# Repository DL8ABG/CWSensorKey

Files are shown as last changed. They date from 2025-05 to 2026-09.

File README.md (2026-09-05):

# Introduction #

This project contains a kit for a CW-key (or morse key) that works without any mechanical parts but is based on electronic sensors. The idea and initial designs comes from [John, M0UKD](https://m0ukd.com/homebrew/capacitive-cw-touch-key-circuits/) and is extended within this project to a complete kit with housing and a construction of a CW sensor pad.

Credits:
- [John, M0UKD](https://m0ukd.com/homebrew/capacitive-cw-touch-key-circuits/) for the great idea and documentation of this tiny circuit
- [Ken, KM4NFQ](https://github.com/km4nfq/capacitive-touch-key) for his design of the circuit board in [KiCad](https://www.kicad.org/), which was the starting point and inspiration for me on this kit
- Stephan, DO2WWW, for his support during the development of this kit
- [Christian, DJ9PH](https://www.qrz.com/db/DJ9PH), for his support during the development of this kit and for designing the housing for 3D printing. It looks great! He also supported the official setup of the kit by the [AATIS](https://www.aatis.de).

# Available as a kit #

The key and the 3D printed housing are available as kit from AATIS as set number [AS686](https://www.aatis.de).

## pieces needed for the complete kit ##

To assemble the complete kit, you need this:
- the fully assembled electronics board (see "[Electronics](#electronics)" section below)
- the assembled CW Sensor Pad (see "[The CW sensor pad](#the-cw-sensor-pad)" section below)
- housing:
  - metal housing Mammond 1550Q see below ["metal Housing"](#metal-housing)
  - 3D printed housing, see below ["3D printed Housing"](#3d-printed-housing)
- 1 holder for 2 batteries AAA (e.g. from [Reichelt](https://www.reichelt.de/de/de/shop/produkt/batteriehalter_fuer_2_microzellen_aaa_loetfahnen-57125))
- 1 switch (e.g. from [Reichelt](https://www.reichelt.de/de/de/shop/produkt/miniatur-kippschalter_ein-aus_3_a_125_v-359360))
- 1 stereo jack for 3,5mm (e.g. from [Reichelt](https://www.reichelt.de/de/de/shop/produkt/klinkeneinbaubuchse_3_5_mm_stereo-7301))
- material for mounting (see ["Options for mounting"](#options-for-mounting) below)

# Electronics #
The board used in this project was initially designed by [John, M0UKD](https://m0ukd.com/homebrew/capacitive-cw-touch-key-circuits/) and the [KiCad](https://www.kicad.org/) file is based on the work of [Ken, KM4NFQ](https://github.com/km4nfq/capacitive-touch-key). It was changed in shape to fit in the housing and make the wiring easy. 

## Bill of electronic parts ##
- 1 x circuit board
- 2 x IRFML8244TRPBF MOSFETs, SMD SOT-23 (Q1, Q2)
- 2 x AT42QT1011 Touch sensors, SMD (U1, U2)
- 2 x 22K Ohm resistors, SMD 1206 (R1, R2)
- 2 x 0.1uF capacitors, SMD 1206 (C1, C3)
- 2 x 2.2nF capacitors, SMD 1206 (C2, C4)

## Building the circuit board ##

During the soldering, be careful due to the small size of the board and parts, not to make short circuits or bridges of solder. Beyond that and due to the small amount of parts, the soldering is an easy thing.

There are some vias in the board to ensure the GND level to be reliability available on all places needed. The back of the board is connected to GND (except the small places for connecting the wires).

The circuit board from the solder side looks like this (picture generated with KiCad):
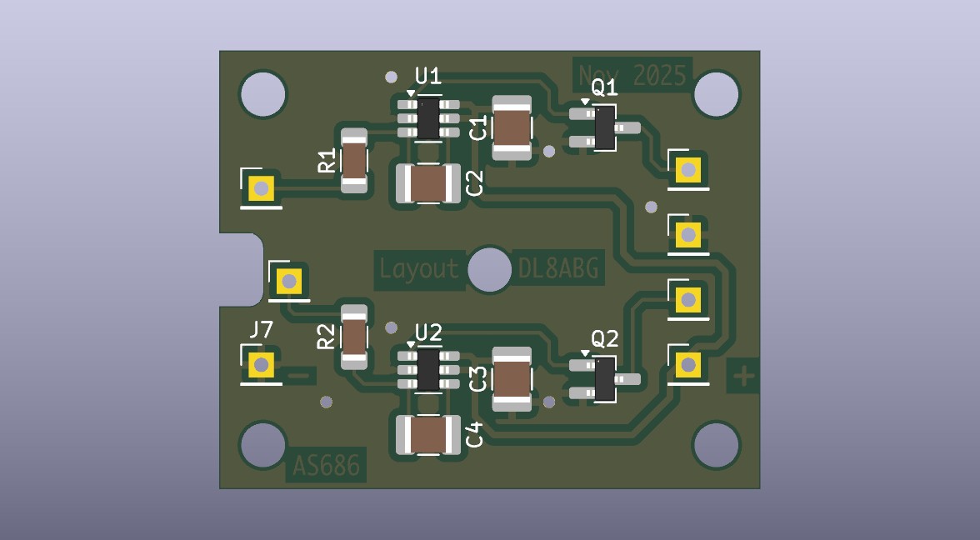
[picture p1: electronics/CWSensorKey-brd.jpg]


The circuit board from the bottom side looks like this (picture generated with KiCad):
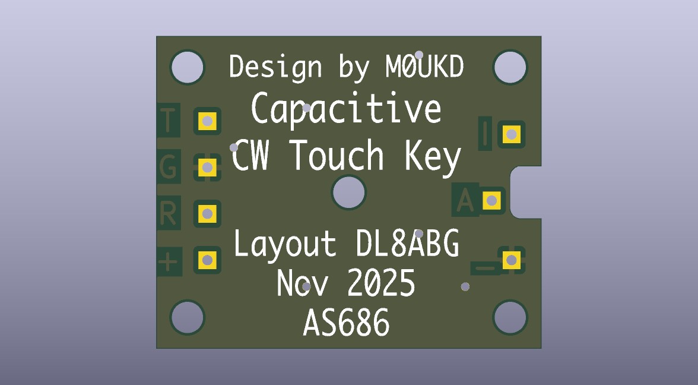
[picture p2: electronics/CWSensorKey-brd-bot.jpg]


The schematic it identical to that of [M0UKD](https://m0ukd.com/homebrew/capacitive-cw-touch-key-circuits/):
The schematic

## Wiring ##

The board has connectors (with its markings on the bottom side which is later visible during installation in the housing): 
- for the sensor pad, marked with I for dit and A for dah
- for the connector, marked with T for tip, R for ring and G for ground of the 3 pin 3,5mm plug
- power supply, marked with + and -

All electrical parts together look like this:
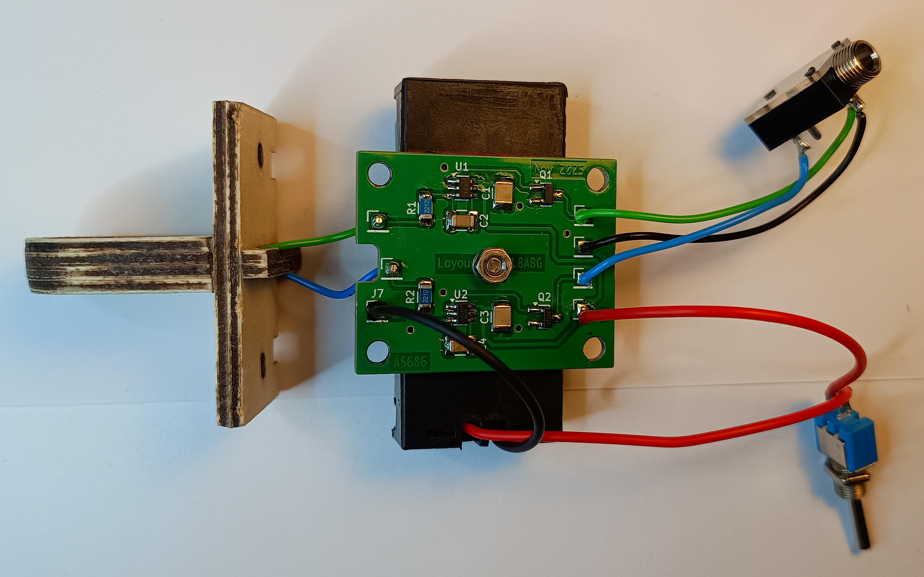
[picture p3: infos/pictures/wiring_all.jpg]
Wiring


You see the battery holder mounted on the bottom side of the board and the switch is inserted in the + cord.

# Mechanics #

## The CW sensor pad ##
The pad is designed to use coins as sensor fields. For Germany/Europe Euro coins are easily accessible. That was the reason, why 10 Euro-Cent coins will fit in the sensor (diameter 19.75mm, width nearly 2mm). If you intend to use other dimensions, adapt the [FreeCAD](https://www.freecad.org/) files as needed.

The sensor pad consists of multiple pieces of 2mm wood to be cut by e.g. a laser cutter. In the development of this kit I found, that the "2mm" plates are only 1.9 mm in with, so the holes for fitting together the single plates are designed for this width. If you have really 2.0 mm wide plates, use a file or a piece of sand paper to adjust the width of the holes to your need.

The sensor pad consists of 6 pieces of wood:
- 2 rectangular holder plates
- 2 middle plates which differ in the position of the "wire channel" from each other
- 2 side plates with round holes to fit the coins

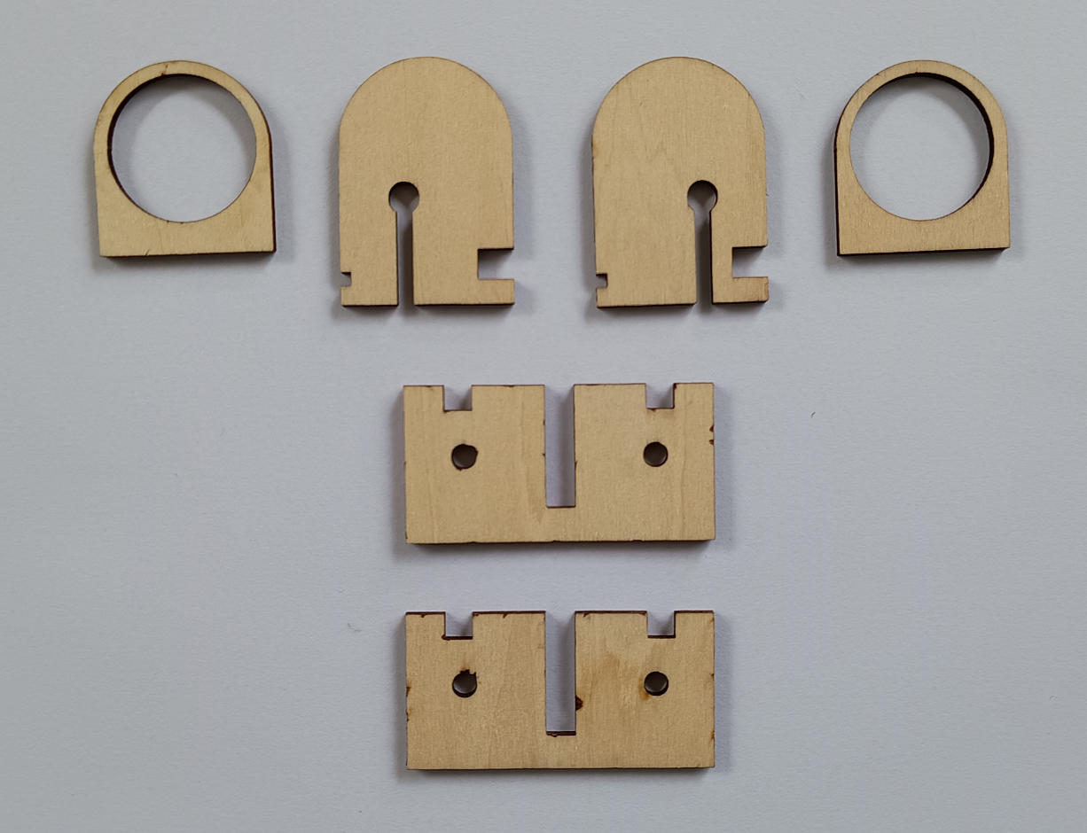
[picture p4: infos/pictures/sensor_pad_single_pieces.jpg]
So this is, what you have


First step:
- glue together the 2 rectangular holders
- glue together the 2 middle plates

Take care that the each two pieces lie exactly on top of each other!

After having glued the first parts, it should look like this:
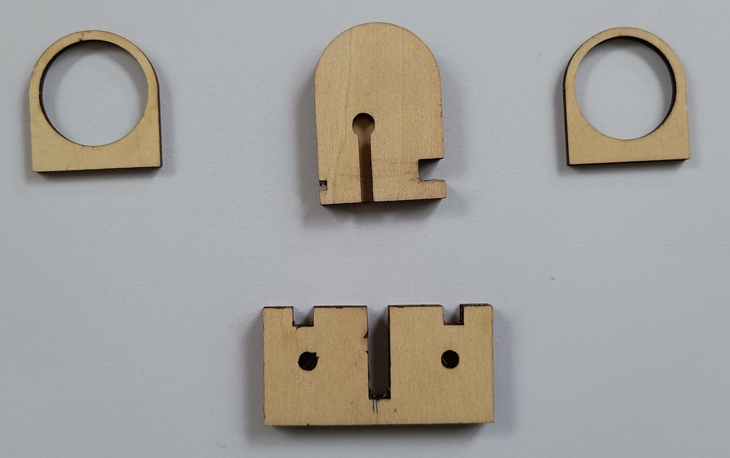
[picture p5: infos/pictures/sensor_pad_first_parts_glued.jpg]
After having glued the first parts, it should look like this


Now glue the side plates on each side of the middle plates. Also here, take care that they lie exactly in the right position.

Now you have two pieces:
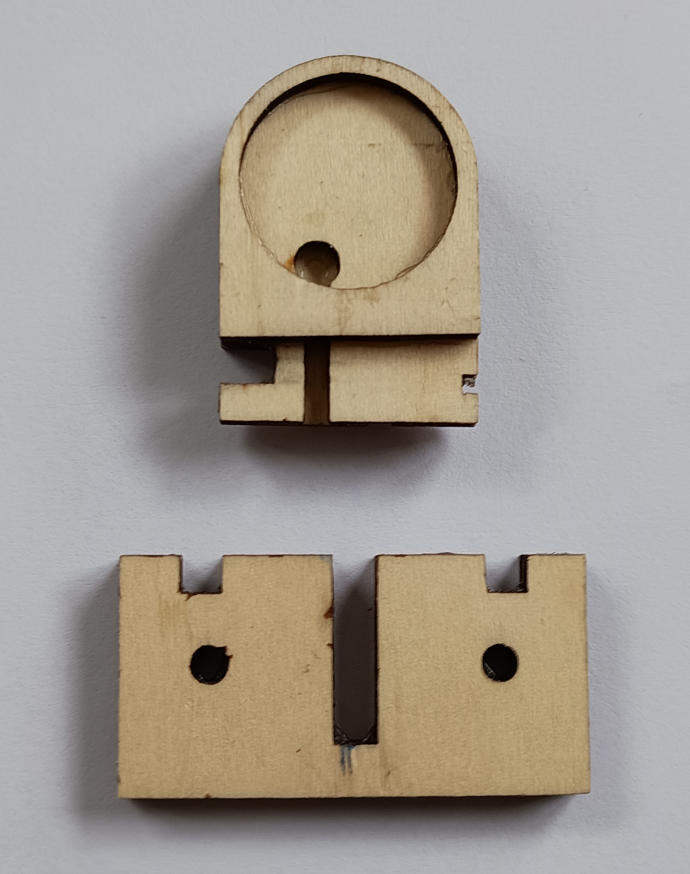
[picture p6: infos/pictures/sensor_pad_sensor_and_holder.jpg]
Now you have two pieces


Now set the holder in the hole at the end of the pad. Take care, that it is directly connected to the back side of the side plates. This ensures the correct alignment in up/down direction. Also take care, that the sensor pad part and the holder have a good rectangular orientation to ensure a correct alignment to the left and right.

Your assembled sensor pad should look like this:
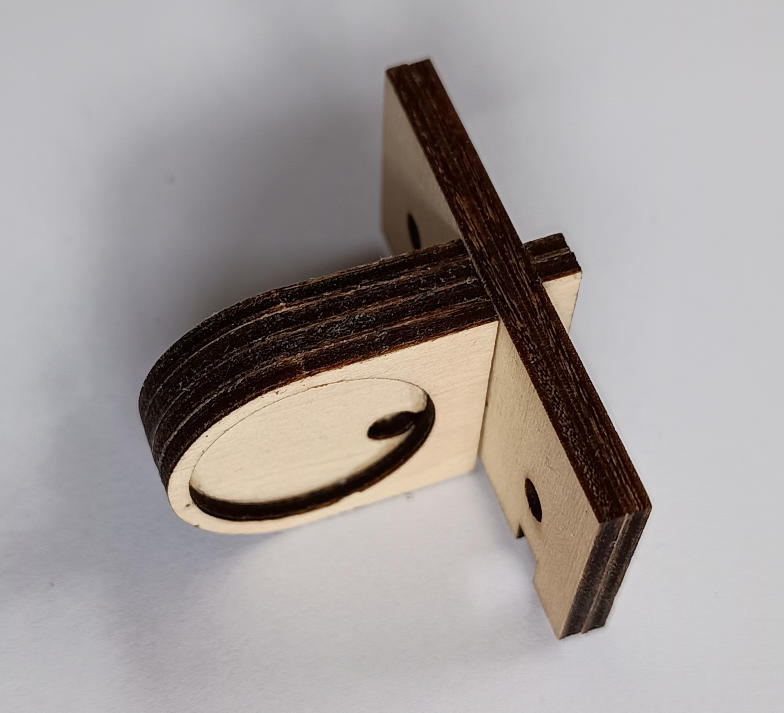
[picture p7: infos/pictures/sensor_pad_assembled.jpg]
The sensor pad is now assembled


The next step is to prepare the coins. Solder the wires on them (next to the edge). The solder spot should be not to big (it must fit in the small hole below the coin in the pad). Prior to soldering, clean the surface of the coin on the place you want to solder with a screwdriver to remove the oxide layer that normally covers the coin.
It should look like this at the end of this step:
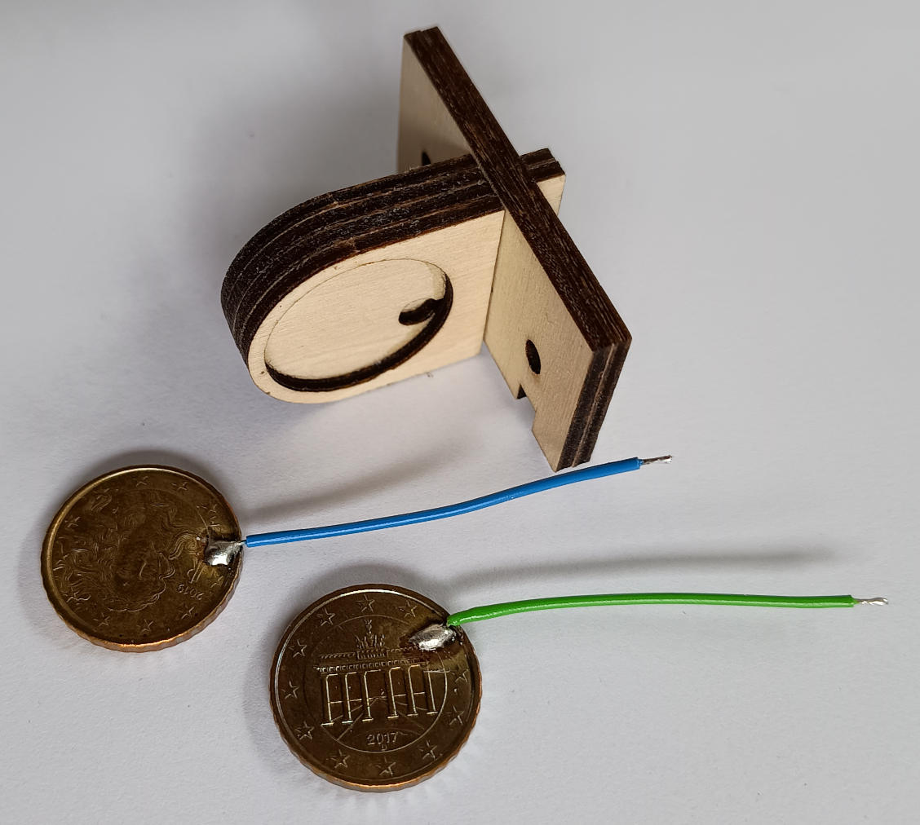
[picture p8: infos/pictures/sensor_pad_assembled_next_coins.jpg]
The sensor pad next to the coins


Now insert the wires in the small holes below the holders of the coins, so that they exit the pad at the back side. The coins should fit perfectly in the holder plates and it should look like this. If there are residue of the glue in the holes for the wires, clean them with a thin drill.
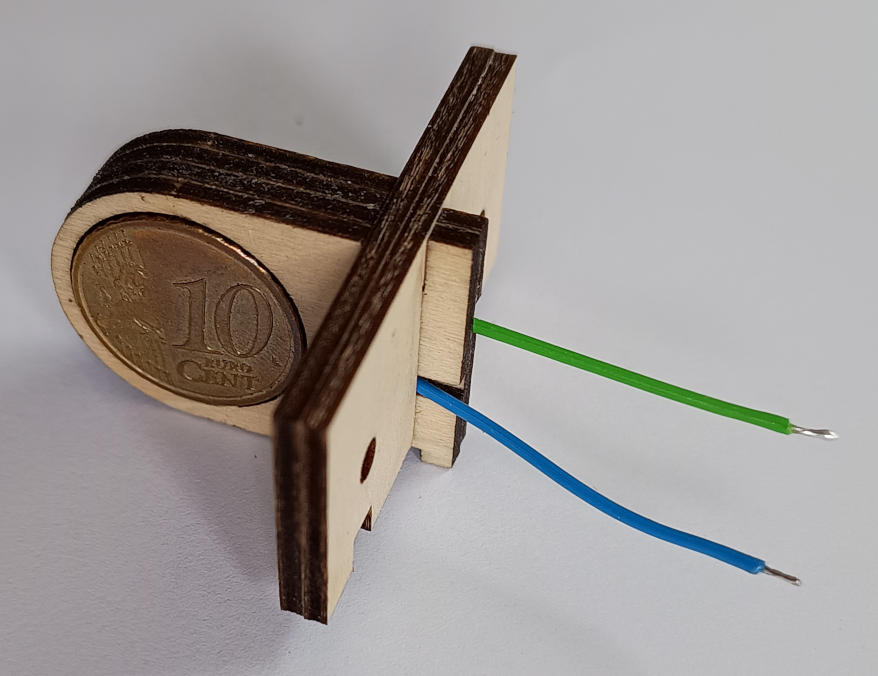
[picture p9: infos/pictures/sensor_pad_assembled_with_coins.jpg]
The sensor pad with coins


Glue the coins in the holder plates and/or use some plastic tape to prevent them from falling out. With that, your sensor pad is complete and can be installed in the housing.

## Metal housing ##

For a metal housing, you need the following components:
- the housing Mammond 1550Q (e.g. from [Reichelt](https://www.reichelt.de/de/de/shop/produkt/alugehaeuse_1550_q_60_x_55_x_30_mm_aluminium-221407))
- 4 distance bolts M2,5 with length 5mm (e.g. from [Reichelt](https://www.reichelt.de/de/de/shop/produkt/distanzbolzen_5_mm_m2_5-236284))
- 4 screws M2,5 x 5mm
- 8 washers for M2,5
- 8 lock washers for M2,5
- 4 nut screws M2,5

- for mounting the CW Sensor Pad, you need:
  - 2 screws M3 x 10mm
  - 2 washers for M3
  - 2 lock washers for M3
  - 2 nut screws for M3

Preparing the Mammond 1550Q

### Hole for sensor paddle ###

First mark the middle of the _wider_ side (green on the next picture).

Than mark nearly 2mm to each side (blue on the next picture). In sum it must meet the width of your paddle. It is ok, if it is a tight fit.
The hight of the marking is 23mm to meet the height of the paddle.

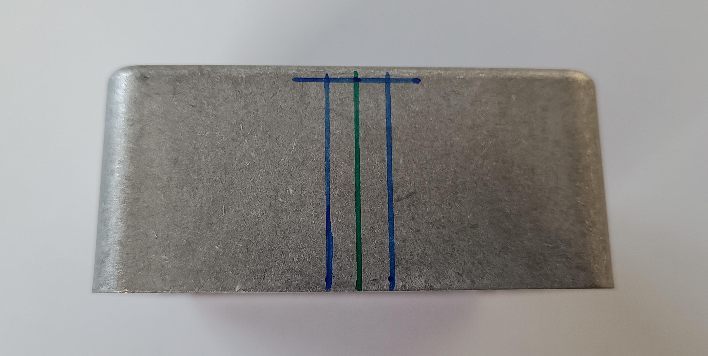
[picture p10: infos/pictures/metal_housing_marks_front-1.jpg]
Markings on the front side


Than take a metal saw to cut out the opening along the outer lines (the blue ones in the picture above). Use a key file to make the opening accurately rectangular.

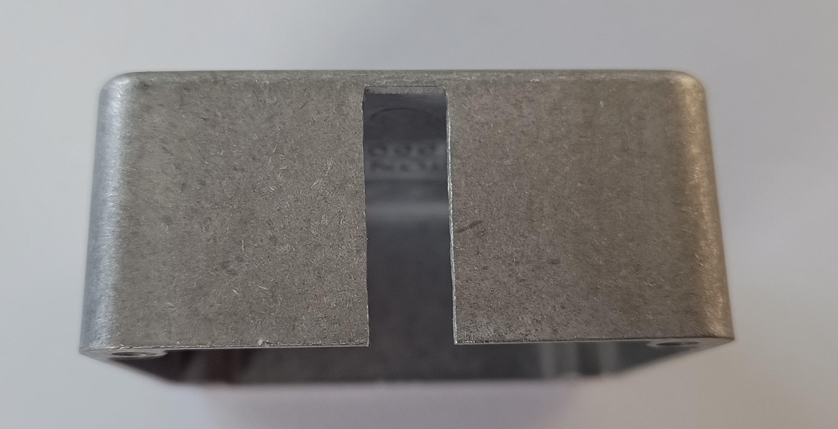
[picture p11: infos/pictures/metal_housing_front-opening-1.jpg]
Opening for the paddle


Next mark the hole for the paddle holder. You can measure it (12mm from the bottom and 30mm apart). To make sure it fits with your holder, additionally place the holder it the opening you just prepared and use the holes in the wooden plates to mark points for the holes (or verify your measurement).

Than drill the holes to fit with the 3mm screws. If you use countersunk screws, also drill the lowering.

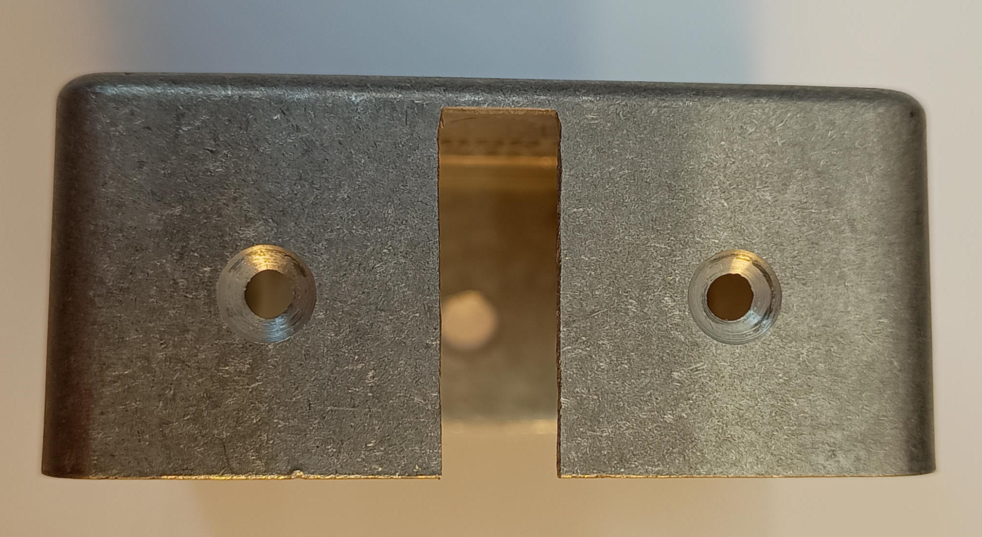
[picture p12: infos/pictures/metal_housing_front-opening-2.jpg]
Opening for the paddle and holes for screws


### Holes for the board ###

Place the paddle in its position (you can also use the screws to temporarily holt it in place). Than lay the circuit board inside the housing and position it so that the holder of the paddle protrudes into the recess.

To have enough room for the switch and connector at the back side, place the circuit board as tight as possible next to the paddle holder.

Mark the points for the holes and drill them to fit the 2.5mm screws. As well here: if you use countersunk screws, also drill the lowering.

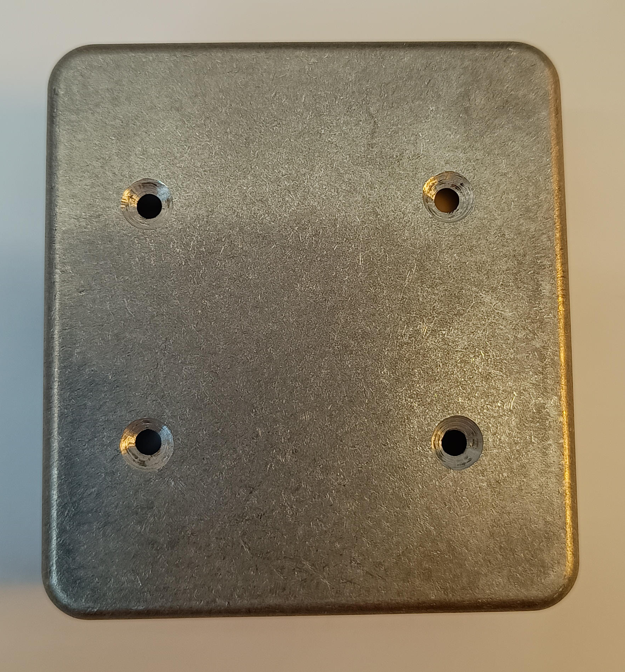
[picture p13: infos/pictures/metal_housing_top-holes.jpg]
Holes for the screws to hold the circuit board


### Holes for connector and switch ###

The positioning of the holes for the connection and the switch is somewhat difficult. 

Depending of the parts you use, they can either be positions on the side next to the circuit board or you can position the connector centered "above" the circuit board and only the switch side next of it.

Be careful to leave enough space for the circuit board with the bolts holding it and the batterie holder, which is placed on top of the circuit board.

This picture shows the installation side next to the board (on one of the prototypes):
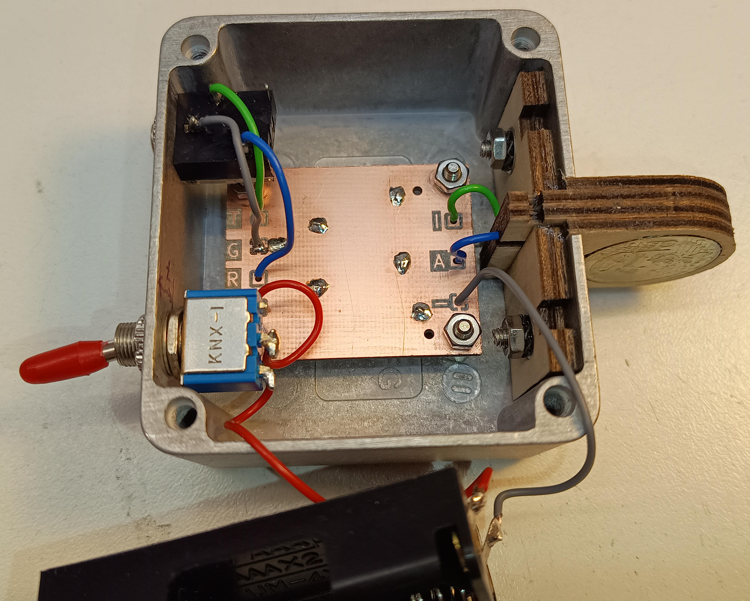
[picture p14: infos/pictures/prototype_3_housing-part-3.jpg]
Connector and switch out of center of the housing


This picture shows the holes for the connector centered and the switch at the side:
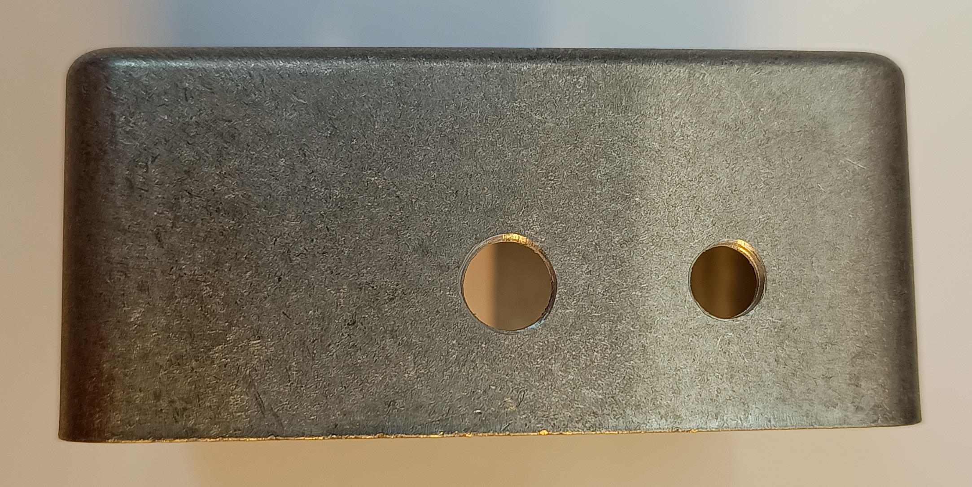
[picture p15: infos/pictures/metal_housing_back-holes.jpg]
Connector centered and switch out of center of the housing


So you can place it as you like it best. For example: according to the hand you want to use the key, place the switch on the side "away" from you to have it out of your way during usage.

### Putting the pieces in the metal housing ###
Here you see the suggested mounting order seen on the third prototype. How to find the places for the holes in the housing will be explained here in a later version of the README.

First set the bolts for holding the board in the housing using lock washers to keep it tight:
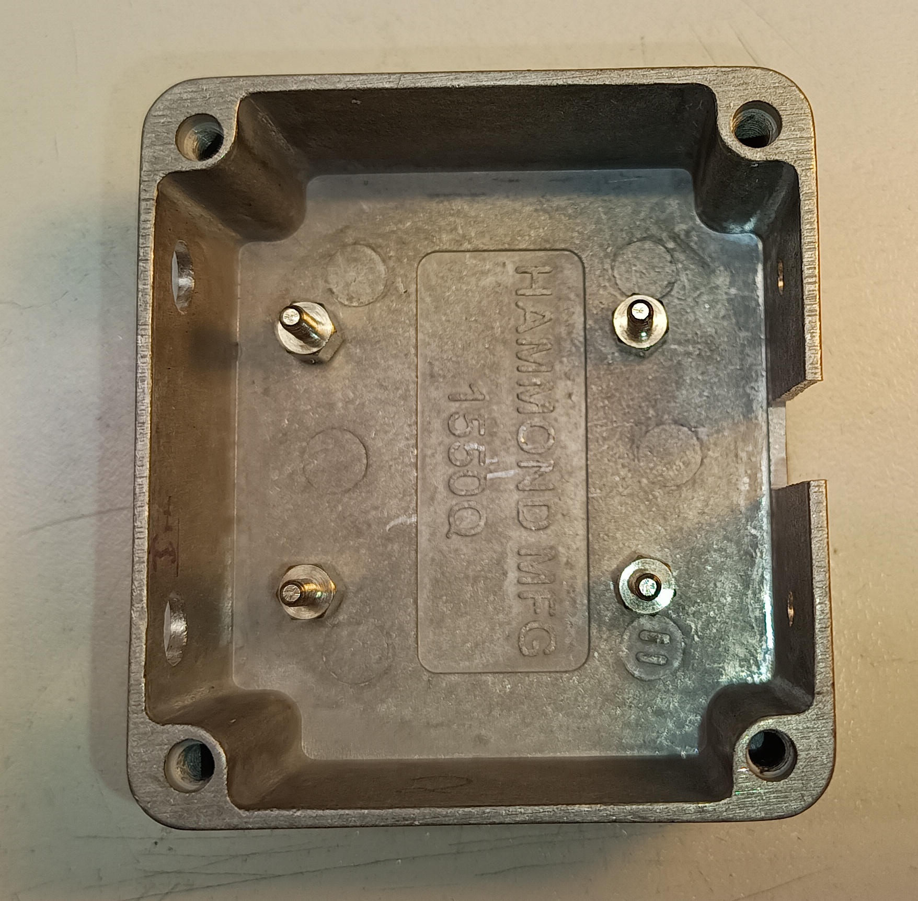
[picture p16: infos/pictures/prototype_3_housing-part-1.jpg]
housing with bolts


Second fix the board on the bolts with the nuts (including washers):
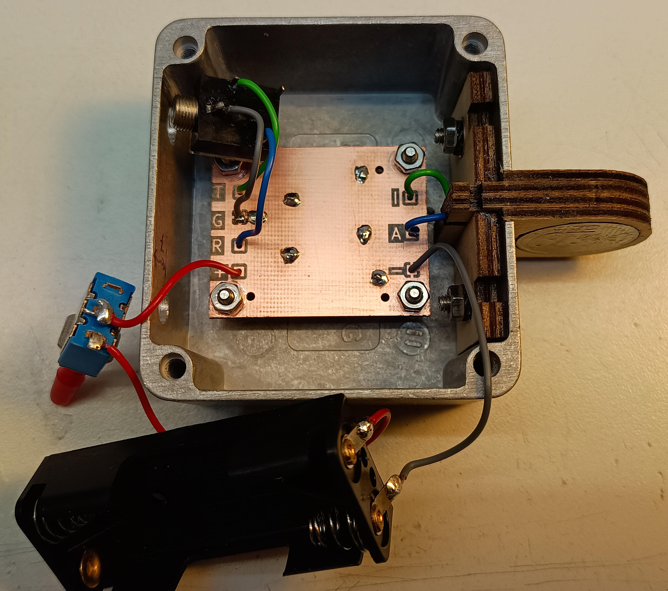
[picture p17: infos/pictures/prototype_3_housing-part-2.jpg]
board on the bolts


Then fix the sensor pad, the connector and the switch in its holes:
additional components fixed

As the last step, mount the battery holder on the board. 

There are two options:
- using some double-sided adhesive tape: Use strong adhesive tape, preferably one with a layer of silicone, which is often recommended for outdoor use.
- use the hole in the center of the board to screw the battery holder to the board. Therefore, you need an _additional_ M2.5 screw with plate, washer plate and nut (not mentioned in the part list on top of the page)

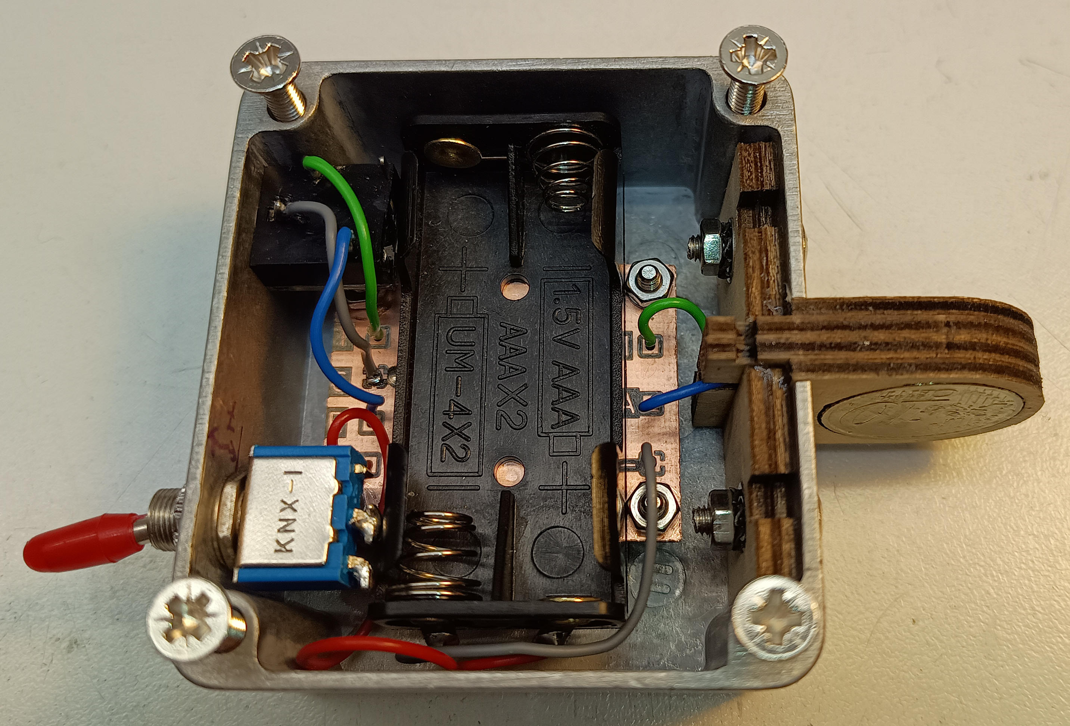
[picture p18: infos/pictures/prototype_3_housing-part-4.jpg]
battery holder fixed


Now you can close the housing and your key is complete (or you want to add magnets as a mounting option, what ist explained in the next section).

## 3D printed housing ##

For the 3D printed housing you need the following:
- 3D printed housing, a bottom and a top part (files to be found under mechanics/housing)
- 12 press-fit sleeves M3
  - 4 of them only if you want to attach magnets below the hosing (see ["Options for mounting"](#options-for-mounting) below)
- 4 screws M3 x 8mm (holding the circuit board)
- 4 screws M3 x min 10mm (connecting the two parts of the hosing)

- for mounting the CW Sensor Pad, you need:
  - 2 screws M3 x 10mm
  - 2 washers for M3
  - 2 lock washers for M3
  - 2 nut screws for M3

The wiring is identical to that when using the metal housing.

### The press-fit sleeves ###

First, the press-fit sleeves must be installed. It is recommend to use an installation aid to ensure that they are pressed in straight. If this is not available, please use a conical soldering iron tip and hold it absolutely straight.

The press-in nuts of the magnet should also be pressed in from the INSIDE to ensure a secure hold.

### The sensor pad ###

The sensor pad is inserted in the rectangular hole in the same way as for the metal housing. The screws are inserted from the outside with plates and washer plates and nuts inside. 

### The electronics ###

This step is similar to that of the metal housing:
- mount the battery holder on the circuit board
- mount both inside the housing using 4 screws

### Connector and switch ###

The holes are prepared in the 3D printed housing. Just insert them and use their screws to fixate them. Some force is needed to make them hold. Be careful that it is tight enough but not to tight to damage them.

## Options for mounting ##
As the kit is intended for universal use, you can decide for which purpose you like to use it in your case. It can be used for portable operation (due to its small size and good closure thus resistance against dirt) or for use in your shack.

For portable use, you can mount strong magnets on the bottom side of the housing. With them you can attach the key to any (magnetic) surface you like (your portable TRX, a metal case, ...). This is the way, many portable keys work (like those from [Palm](https://www.eham.net/reviews/view-product/11153) or other companies).

Possible sources for the magnets are (listed as *examples*)
- [Supermagnete](https://www.supermagnete.de/neodym-magnete-zum-anschrauben/quadermagnet-zum-anschrauben-40-x-20-x-4mm_CS-Q-40-20-04-N)
- [Amazon](https://www.amazon.de/dp/B08F54YGC9)

This is, how it can look:
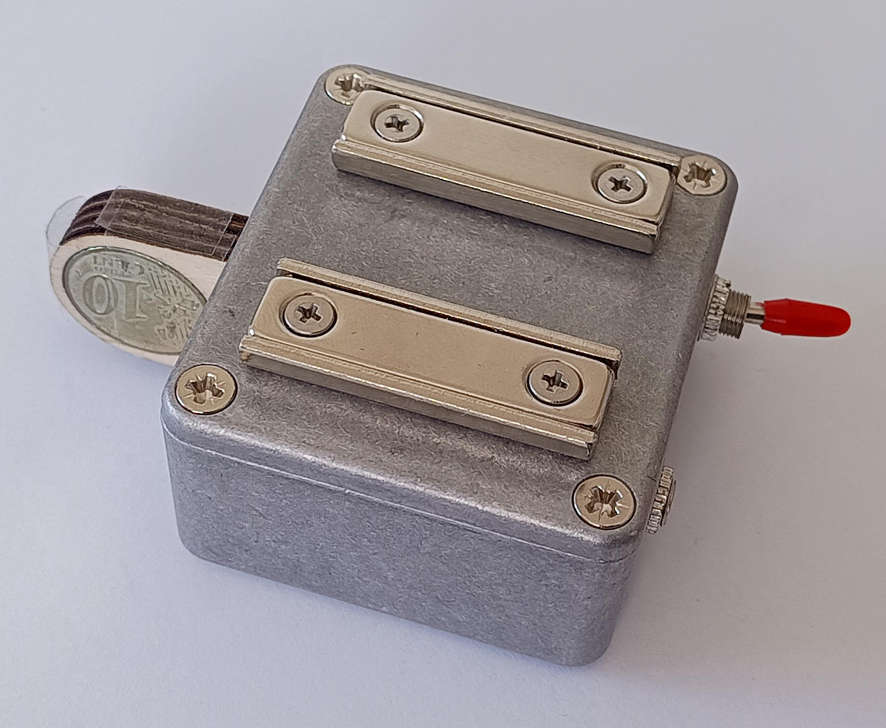
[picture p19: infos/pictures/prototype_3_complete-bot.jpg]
magnets on the bottom side of the housing


For use only in your shack, you can mount the bottom side of the key directly to a heavy item like a metal plate (e.g. steal with 8cm x 8cm x 2cm) or a stone plate, with probably looks great). For this mounting, you drill holes according to the holes for the screws in the housing through yor item and replace the screws of the housing with longer ones suitable for your item dimension. In this way you mount your item, the bottom of the housing and the top of the housing in once.

# Hints #
## Battery falling out of holder when mounting the key with strong magnets ##

If you have very strong magnets, it can happen, that the batteries fall out of its holder if you attach the key to a surface. To avoid this, put some foam on top of the batteries to tighten their position together with the bottom of the housing.

# History #

## First Prototype ##
The first prototype is shown here. It was my first try on how good the circuit works and was made by parts I found after receiving the board. I also verified with this construction, that coins are suitable sensor pads (here 5 Euro-Cent coins).
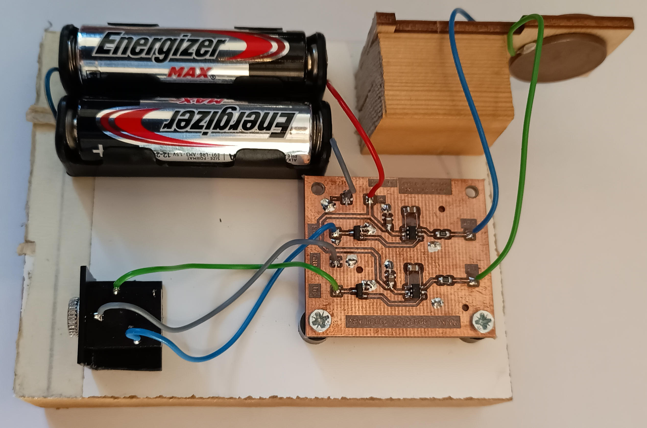
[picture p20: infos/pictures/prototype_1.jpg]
first prototype of the kit


## Second Prototype ##
I changed the first prototype by replacing the "testing" sensor pad with first example made from laser cutted wood.
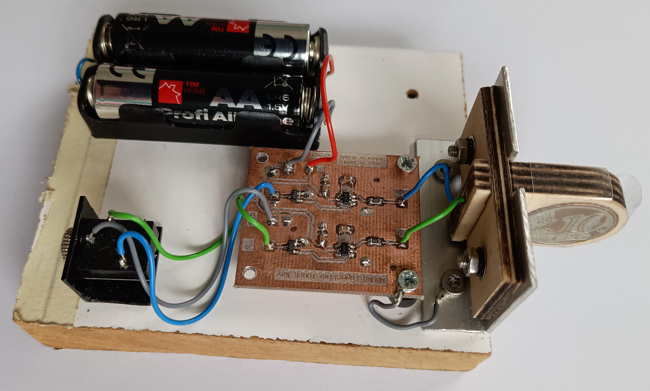
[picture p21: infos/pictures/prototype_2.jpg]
second prototype of the kit


## Third prototype ##
After some changes to the board to reduce its size and place the solder pads on either sides, the third prototype became available. Here you see its construction.

This is the electronic connected with all external components:
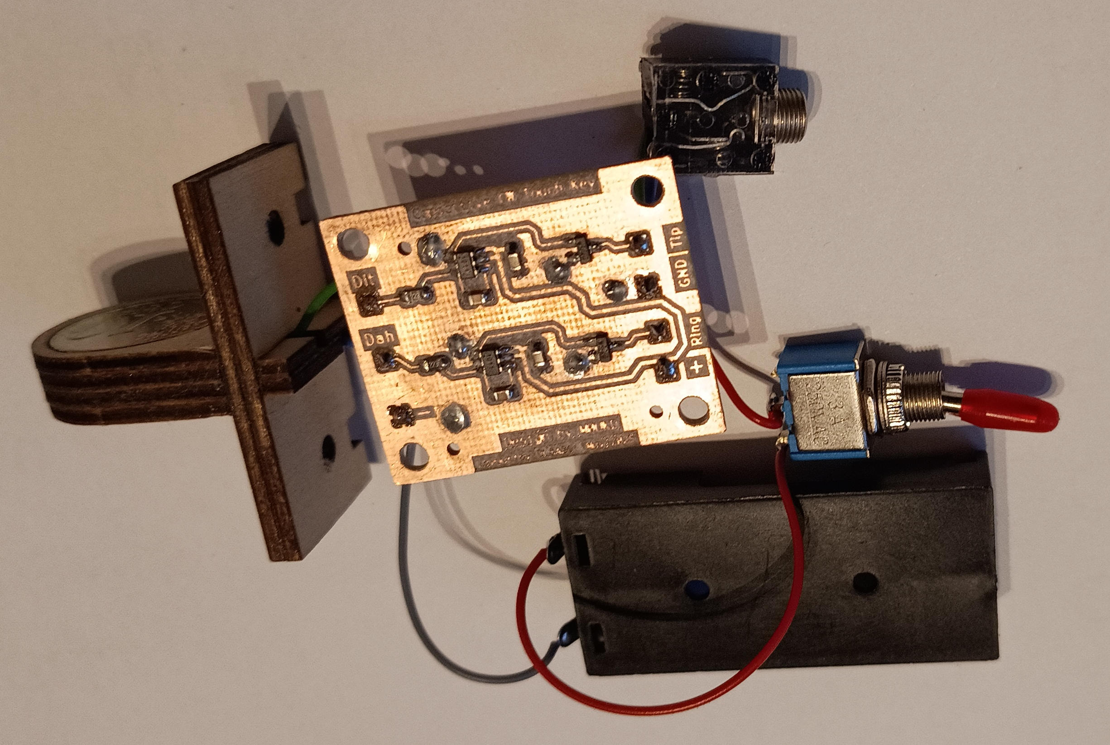
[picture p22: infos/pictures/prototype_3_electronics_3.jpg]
the electronic seen from the solder side


This is the same showing the bottom side of the board (where the battery holder is glued on):
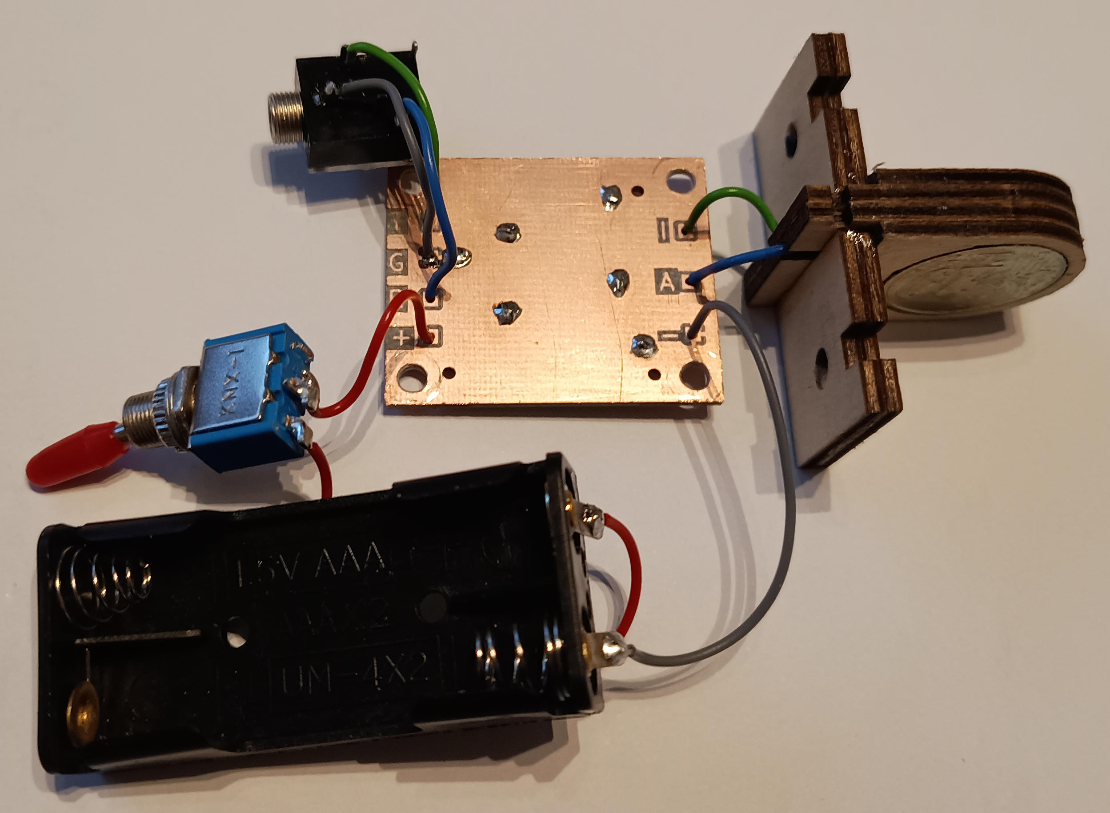
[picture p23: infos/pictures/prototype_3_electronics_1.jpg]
the electronic seen from the bottom side


And theses are pictures of the whole key in its housing:
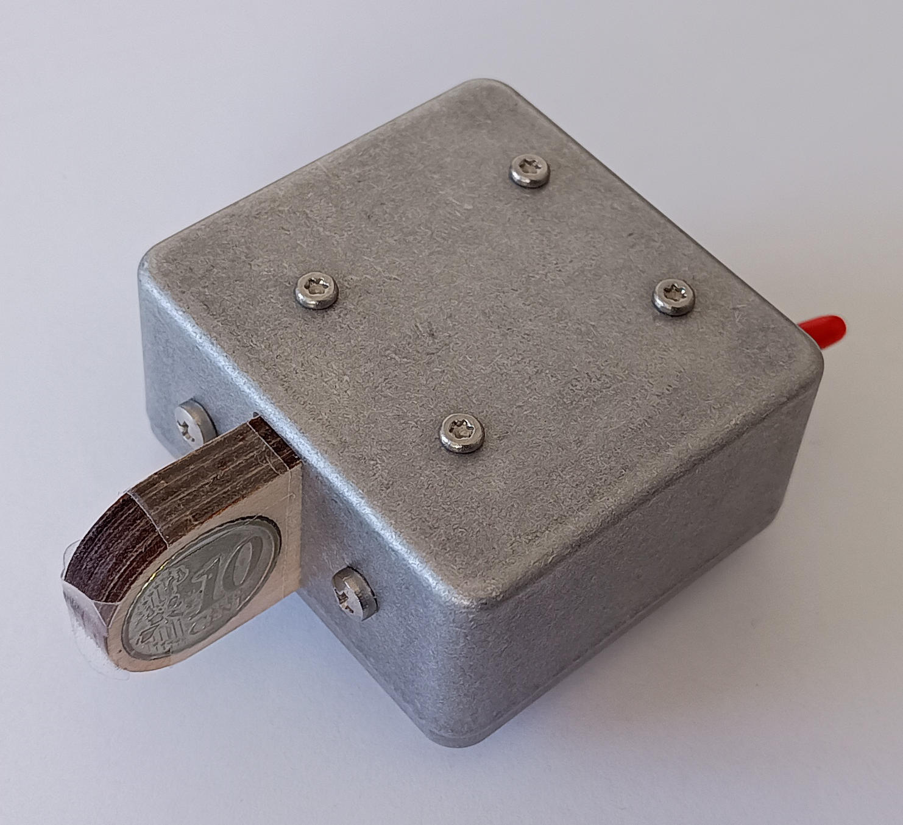
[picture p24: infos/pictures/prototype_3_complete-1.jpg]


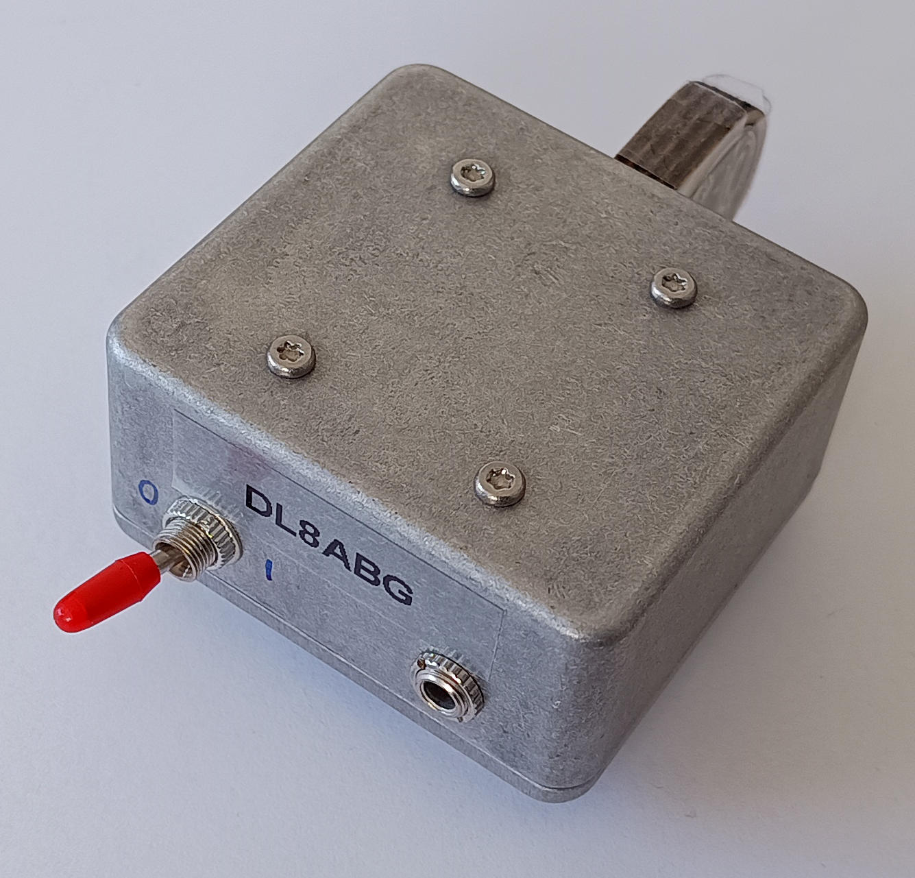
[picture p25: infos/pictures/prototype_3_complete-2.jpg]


## Version 4 ##
As this is more than an "prototype" I call ist version 4 ;-)

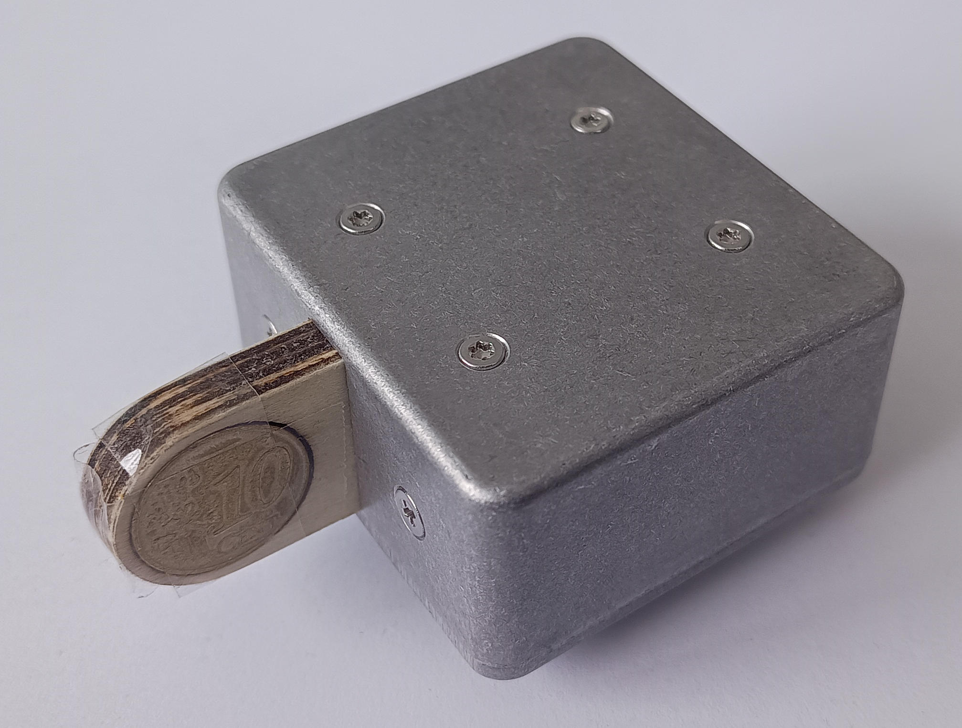
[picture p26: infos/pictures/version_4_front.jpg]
the key seen from front


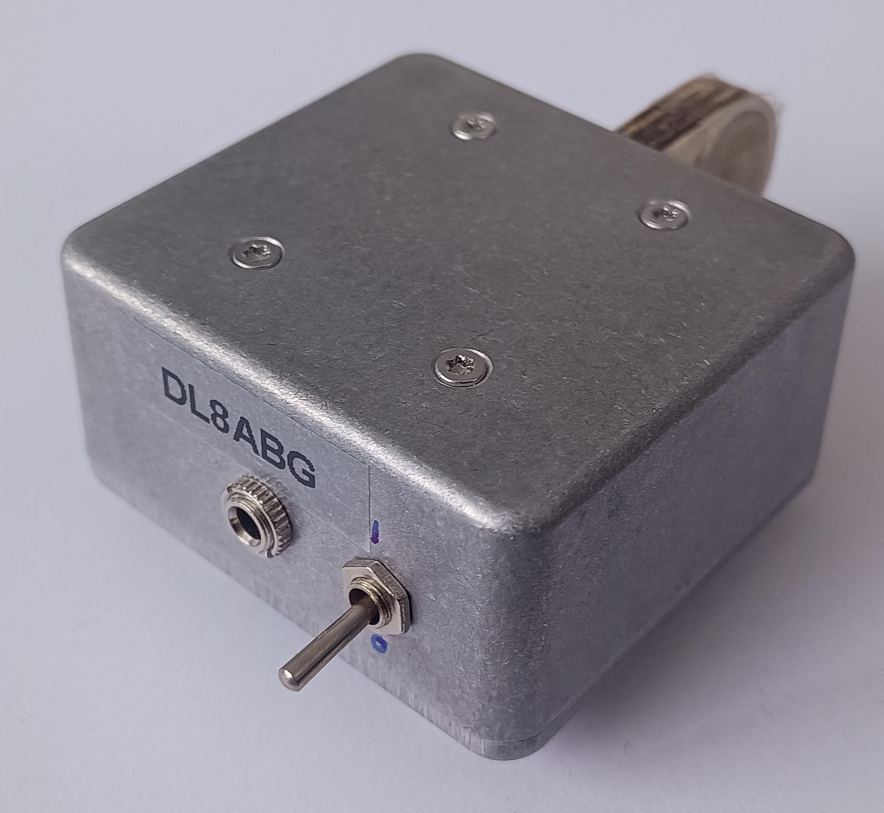
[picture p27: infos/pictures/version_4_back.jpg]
the key seen from back


# Responsibility #
This kit is build by **you**. You are responsible for all safety and legal aspects on setup and operation!! 

The author is not liable for anything, as he only shows his ideas on how such a sensor key can be build.

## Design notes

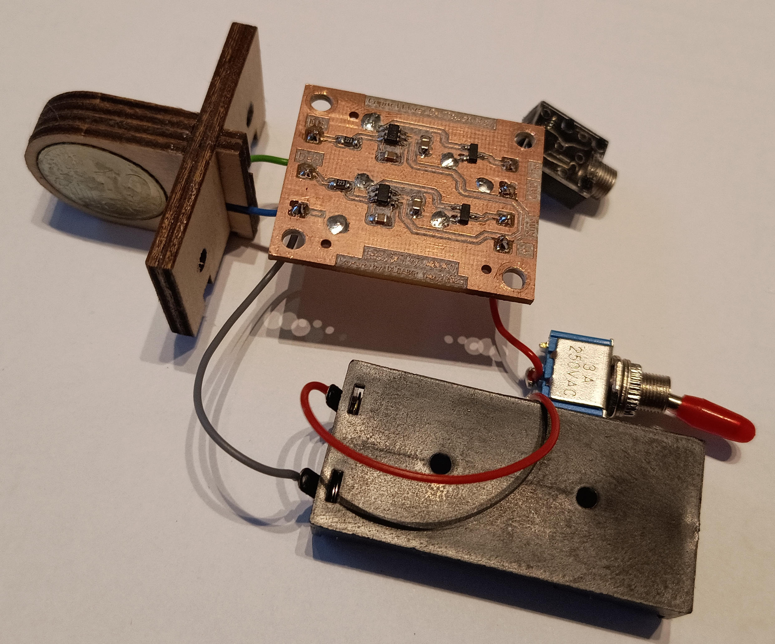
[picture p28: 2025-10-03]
infos/pictures/prototype_3_electronics_2.jpg

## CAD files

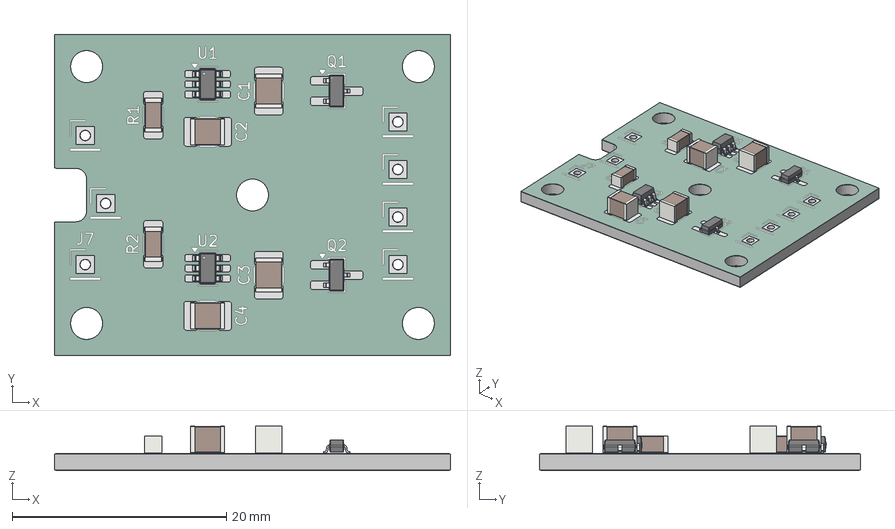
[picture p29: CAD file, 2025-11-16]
electronics/CWSensorKey-brd-3D.step
37.0 x 30.0 x 4.17 mm
C_1210_3225Metric x 4
SOT-23-6 x 2
SOT-23 x 2
C_1206_3216Metric x 2
CWSensorKey_copper
CWSensorKey_pad
CWSensorKey_via
CWSensorKey_silkscreen x 2
CWSensorKey_soldermask x 2
CWSensorKey_PCB

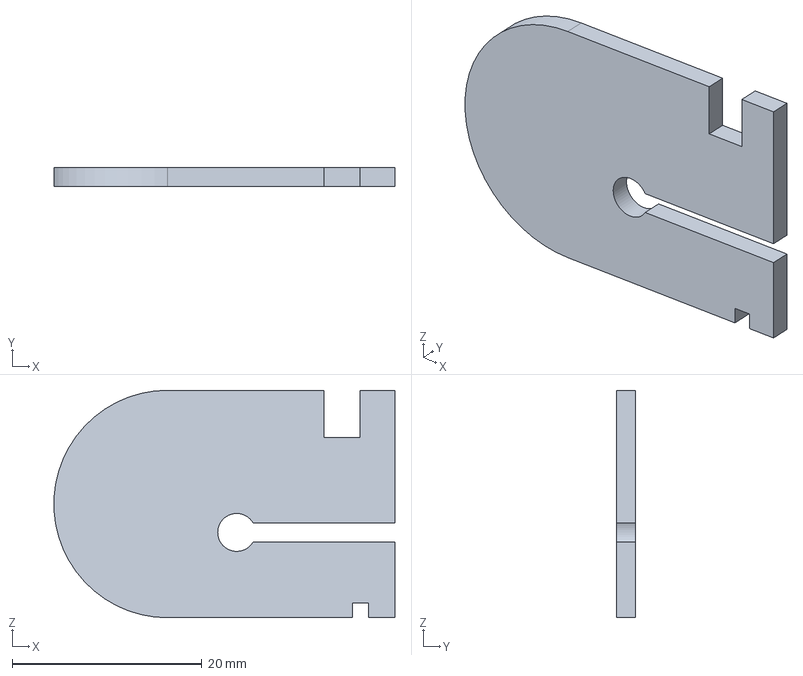
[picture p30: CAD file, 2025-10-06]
mechanics/cwpad/CW-Pad-Middle-Dah.FCStd
36.0 x 2.00 x 24.0 mm

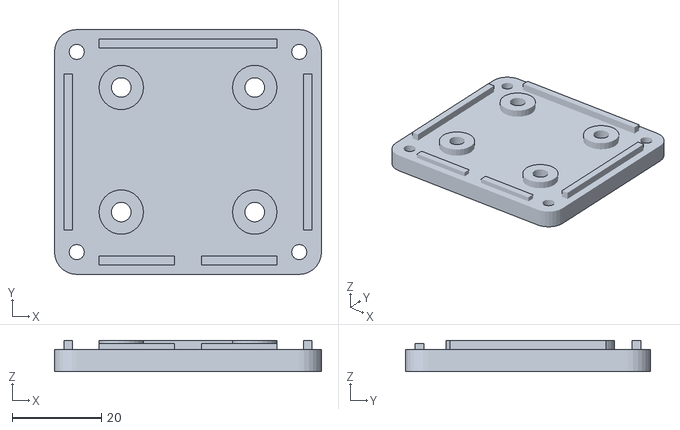
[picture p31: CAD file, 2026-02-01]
mechanics/housing/AS686_Bottom.stl
60.0 x 55.0 x 7.00

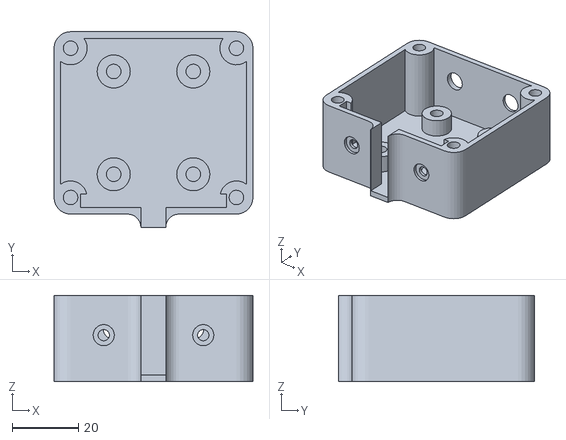
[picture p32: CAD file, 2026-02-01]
mechanics/housing/AS686_Top.stl
60.0 x 59.0 x 26.0

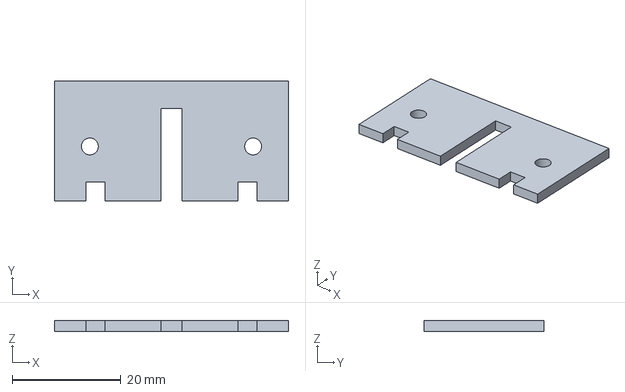
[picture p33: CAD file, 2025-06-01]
mechanics/cwpad/CW-Pad-Holder.FCStd
43.0 x 22.0 x 2.00 mm

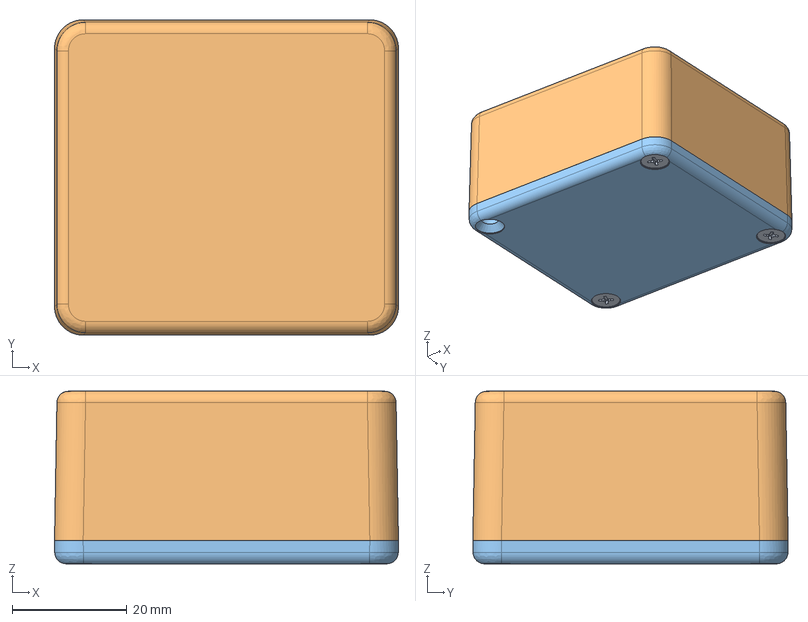
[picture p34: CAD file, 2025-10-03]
mechanics/cwpad/ignore/Housing-Box-with-Parts.FCStd
60.0 x 55.0 x 30.1 mm
SC1550 (screw M3.5-0.6X 12mm FH) x 3
Lid

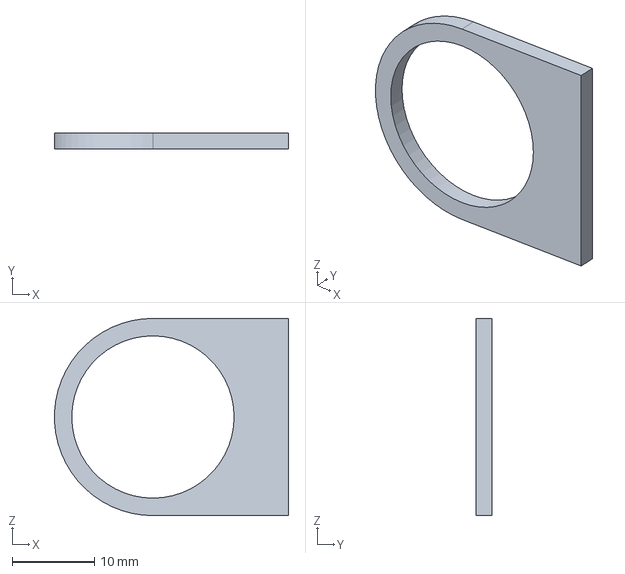
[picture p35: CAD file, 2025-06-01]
mechanics/cwpad/CW-Pad-Side.FCStd
28.5 x 2.00 x 24.0 mm

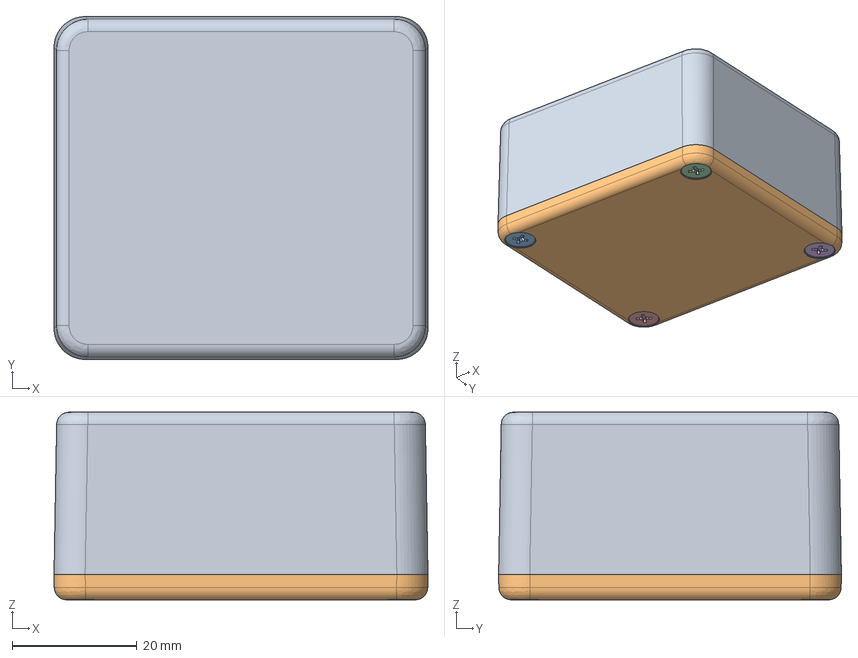
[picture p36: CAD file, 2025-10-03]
mechanics/cwpad/ignore/Housing-Box.FCStd
60.0 x 55.0 x 30.1 mm
1550Q BOX
1550Q LID
SC1550 (screw M3.5-0.6X 12mm FH)
SC1550 (screw M3.5-0.6X 12mm FH)001
SC1550 (screw M3.5-0.6X 12mm FH)002
SC1550 (screw M3.5-0.6X 12mm FH)003

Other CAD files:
mechanics/cwpad/ignore/CWSensorKey-Assembly.FCStd
mechanics/cwpad/ignore/Pad-Assembly.FCStd
mechanics/CWSensorKey-brd-3D.step
mechanics/cwpad/CW-Pad-Middle-Dit.FCStd
mechanics/cwpad/ignore/CW-Pad-Basic.FCStd
mechanics/cwpad/ignore/1550Q.stp
electronics/CWSensorKey-brd-3D.stl
mechanics/cwpad/ignore/1550Q.igs

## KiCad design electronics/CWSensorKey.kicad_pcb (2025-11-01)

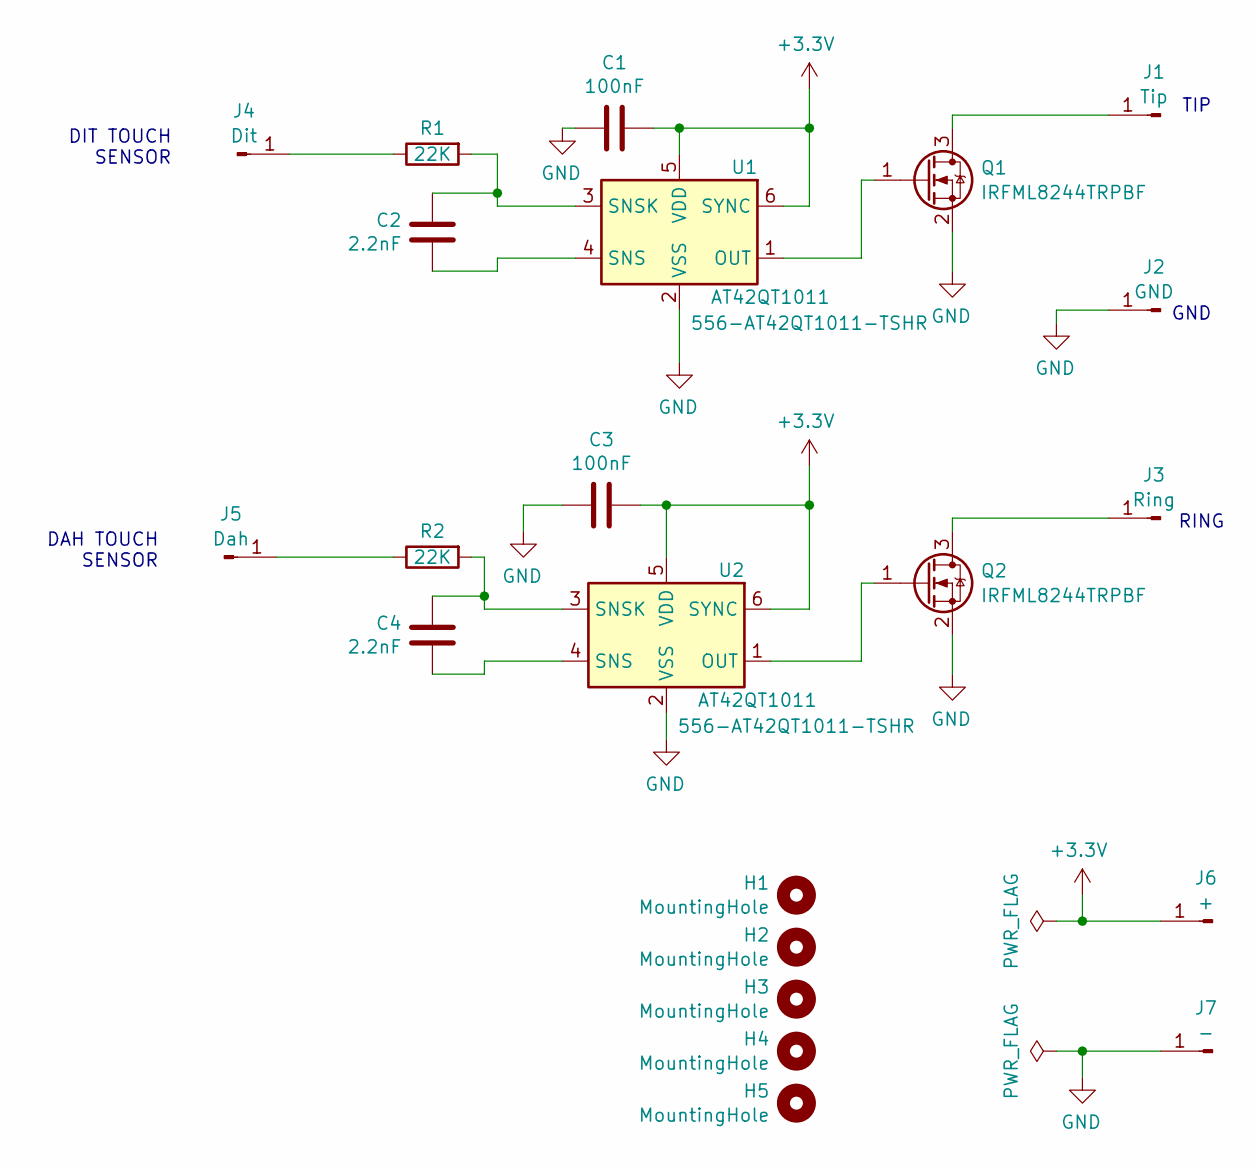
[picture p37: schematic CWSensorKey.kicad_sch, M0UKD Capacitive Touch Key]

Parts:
C1, C3: 100nF; C_1210_3225Metric_Pad1.33x2.70mm_HandSolder
C2, C4: 2.2nF; C_1210_3225Metric_Pad1.33x2.70mm_HandSolder
H1, H2, H3, H4, H5: MountingHole; MountingHole_3mm
J1: Tip; PinHeader_1x01_P2.54mm_Vertical
J2: GND; PinHeader_1x01_P2.54mm_Vertical
J3: Ring; PinHeader_1x01_P2.54mm_Vertical
J4: Dit; PinHeader_1x01_P2.54mm_Vertical
J5: Dah; PinHeader_1x01_P2.54mm_Vertical
J6: +; PinHeader_1x01_P2.54mm_Vertical
J7: -; PinHeader_1x01_P2.54mm_Vertical
Q1, Q2: IRFML8244TRPBF; SOT-23_Handsoldering
R1, R2: 22K; C_1206_3216Metric_Pad1.33x1.80mm_HandSolder
U1, U2: AT42QT1011; SOT-23-6_Handsoldering

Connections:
+3.3V: C1.2, C3.2, J6.1, U1.5 (VDD), U1.6 (SYNC), U2.5 (VDD), U2.6 (SYNC)
GND: C1.1, C3.1, J2.1, J7.1, Q1.2 (S), Q2.2 (S), U1.2 (VSS), U2.2 (VSS)
unnamed: J1.1, Q1.3 (D)
unnamed: J3.1, Q2.3 (D)
unnamed: J4.1, R1.1
unnamed: J5.1, R2.1
unnamed: Q1.1 (G), U1.1 (OUT)
unnamed: Q2.1 (G), U2.1 (OUT)
unnamed: C2.2, U1.4 (SNS)
unnamed: C2.1, R1.2, U1.3 (SNSK)
unnamed: C4.2, U2.4 (SNS)
unnamed: C4.1, R2.2, U2.3 (SNSK)

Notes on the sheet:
GND
DAH TOUCH SENSOR
TIP
RING
DIT TOUCH SENSOR

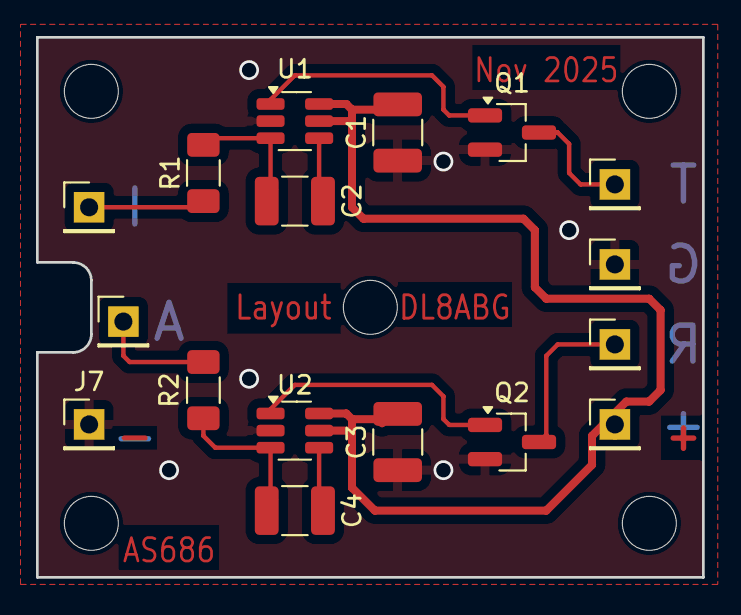
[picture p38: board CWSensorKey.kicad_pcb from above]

Board: 2 copper layers, 37.0 x 30.0 mm, 22 parts (0 on the bottom side), 12 nets.

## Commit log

2025-05-17 Added first files
    [1550Q.igs, 1550Q.stp, CW-Pad-Basic.FCStd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]
2025-05-23 Changed CW-Pad and added script for 2D generation in FreeCAD
    [CW-Pad-Basic.FCStd, CW-Pad-Holder.FCStd, CW-Pad-Middle-Dah.FCStd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]
2025-05-23 Changed holder to fit in housing
    [CW-Pad-Holder.FCStd, CW-Pad-Middle.FCStd]
2025-05-23 generated new gerbers files
    [CWSensorKey-B_Cu.gbl, CWSensorKey-B_Mask.gbs, CWSensorKey-B_Paste.gbp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]
2025-05-29 Extended Readme, slight changes to scripts and other parts
    [CW-Pad-Basic.FCStd, CW-Pad-Middle-Dah.FCStd, CW-Pad-Middle-Dit.FCStd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]
2025-05-29 Changed distance between screws in holder to a more convenient value. Typos in Readme
    [CW-Pad-Holder.FCStd]
2025-05-30 Completed description on building the sensor pad. Added photo of the second prototype.
2025-06-01 Further documentation in README.md Slightly changed dimensions of sensor pad Changed distance betw screws in sensor pad holder
    [CW-Pad-Basic.FCStd, CW-Pad-Holder.FCStd, CW-Pad-Middle-Dah.FCStd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]
2025-10-03 Additional Information on third prototype and slight changes to the board
    [Housing-Box-with-Parts.FCStd, Housing-Box.FCStd]
2025-10-03 index on main: b7a867d Further documentation in README.md Slightly changed dimensions of sensor pad Changed distance betw screws in sensor pad holder (#1)
    [CWSensorKey-B_Cu.gbl, CWSensorKey-B_Mask.gbs, CWSensorKey-B_Paste.gbp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]
2025-10-06 Delete electronics/gerbers directory
    Resolved conflicts
    [CWSensorKey-B_Cu.gbl, CWSensorKey-B_Mask.gbs, CWSensorKey-B_Paste.gbp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]
2025-10-06 Branch (#3)
    * index on main: b7a867d Further documentation in README.md Slightly changed dimensions of sensor pad Changed distance betw screws in sensor pad holder
    * Adapted board for better fitting in the housing
    Implemented script for generation of all 2D files from the KiCad models
    * Delete electronics/gerbers directory
    resolving merge conflict
    * Update CWSensorKey.kicad_prl
    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
    [CW-Pad-Middle-Dah.FCStd, CW-Pad-Middle-Dit.FCStd, CWSensorKey.kicad_pcb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]
2025-10-06 Regenerated gerber files for new board
    [CWSensorKey-B_Cu.gbl, CWSensorKey-B_Mask.gbs, CWSensorKey-B_Paste.gbp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]
2025-10-23 - Changed SMD resistors and capacitors to 1206 as this size is available within the kit from AATIS - Added picture of the board for better overview on github
    [CWSensorKey-B_Cu.gbl, CWSensorKey-B_Mask.gbs, CWSensorKey-B_Paste.gbp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]
2025-10-23 Zip of (old) gerber files removed
2025-11-01 - added option for mounting battery holder to board with screw - added information on AATIS kit number
    [CWSensorKey-B_Cu.gbl, CWSensorKey-B_Mask.gbs, CWSensorKey-B_Paste.gbp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]
2025-11-01 Updated date in schematic
    [CWSensorKey.kicad_sch]
2025-11-16 Cleaning up directory for mechanical components
    [1550Q.igs, 1550Q.stp, CW-Pad-Basic.FCStd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]
2025-11-16 sorting things, where they belong :-)
    [CWSensorKey-brd-3D.step, CWSensorKey-brd-3D.stl]
2026-02-01 Further documentation and reorganisation of the files in mechanic directory
    [1550Q.igs, 1550Q.stp, AS686_Bottom.stl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]
2026-02-01 even more documentation and an additional picture of the board
2026-02-01 added photos of the current version
